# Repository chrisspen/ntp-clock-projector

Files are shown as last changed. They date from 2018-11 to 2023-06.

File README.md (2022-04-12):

NTP Projection Clock
====================

A NodeMCU based clock that wirelessly connects to your network and runs
an NTP client to retrieve the time and project it onto a wall or ceiling.

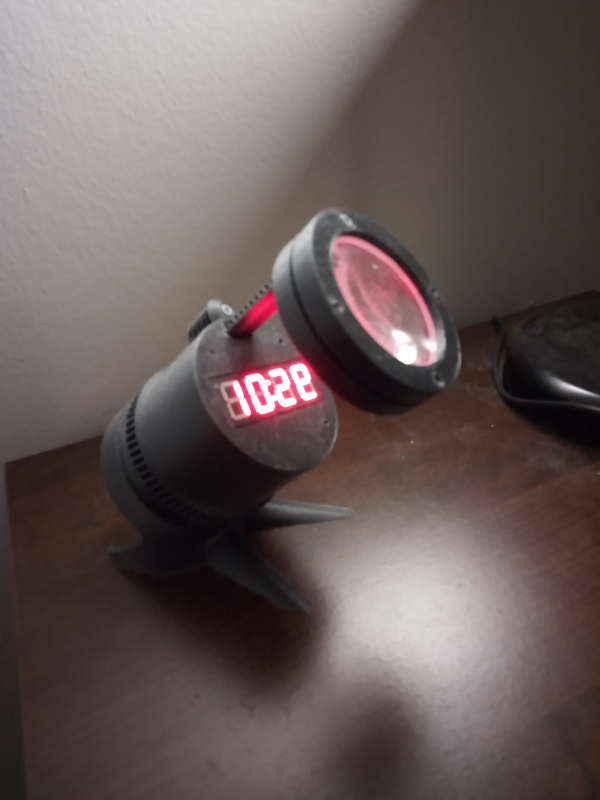
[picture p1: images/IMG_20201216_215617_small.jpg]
ntp projection clock


Construction
------------

Print the [stl files](tree/master/models/printable) that comprise the chassis.

Wire the NodeMCU and Adafruit LED Backback like:

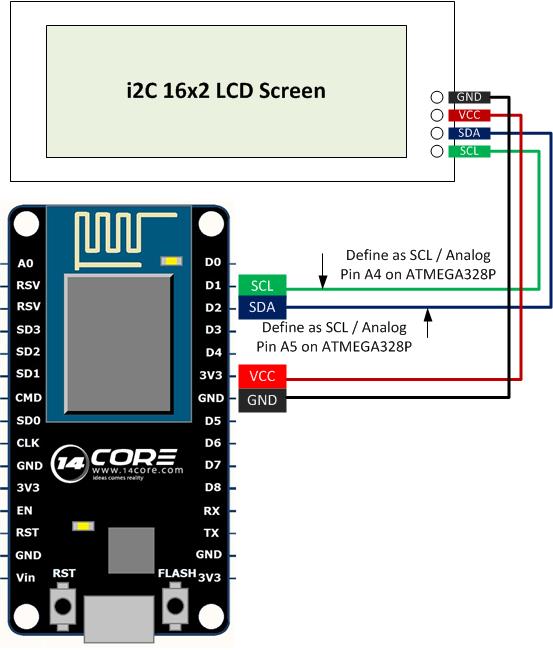
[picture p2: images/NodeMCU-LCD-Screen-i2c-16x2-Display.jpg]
wiring diagram


Screw these boards into the chassis and then plug the NodeMCU into your computer via a USB cable for programming.

The lens I used was the 10x lens piece found ing the <a target="_blank" href="https://www.amazon.com/iMagniphy-Illuminated-Magnifying-Magnifier-Degeneration/dp/B018I1S2Q6/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">iMagniphy Glass</a>. Note, it's actually made of two lens sandwiched in a housing.

Programming
-----------

Install the Arduino IDE 1.8 or later and NodeMCU Arduino support:

    https://www.arduino.cc/

Launch the IDE with:

    cd /usr/share/arduino; arduino

Install [NodeMCU Arduino Support](https://github.com/esp8266/Arduino#installing-with-boards-manager):

* Start Arduino and open Preferences window.
* Enter http://arduino.esp8266.com/stable/package_esp8266com_index.json into Additional Board Manager URLs field. You can add multiple URLs, separating them with commas.
* Open Boards Manager from Tools->Board menu and install or update the esp8266 platform.
* Under Tools->Boards, select "NodeMCU 1.0 (ESP-12E Module)".

Load the `firmware.ino` sketch, select NodeMCU board and board, verify and upload.

To set the Wifi password dynamically, shell into the `scripts` directory and run:

    cd src/scripts
    ./init_virtualenv.sh
    . .env/bin/activate
    ./clock_controller.py login ssid ssidpwd

Otherwise, create the file src/firmware/credentials.h and enter your credentials there, recompile and upload your firmware.

Debugging
---------

To inspect output, select "Serial Monitor" under Tools in Arduino IDE. Select 115200 baudrate.

Also, via the clock_controller.py script with:

    ./clock_controller.py monitor

To get detailed time output:

    ./clock_controller.py time

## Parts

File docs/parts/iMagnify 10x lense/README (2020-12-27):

iMagnify 10x Lense

https://www.amazon.com/gp/product/B018I1S2Q6

iMagniphy LED Illuminated Magnifying Glass Set. Best Magnifier With Lights for Seniors, Macular Degeneration, Reading and Hobbyists (2-Lens (10X + 5X))

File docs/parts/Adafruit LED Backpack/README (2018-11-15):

Adafruit 0.56" 4-Digit 7-Segment Display w/I2C Backpack - Red

https://www.adafruit.com/product/878

https://learn.adafruit.com/adafruit-led-backpack/

https://github.com/adafruit/Adafruit_LED_Backpack

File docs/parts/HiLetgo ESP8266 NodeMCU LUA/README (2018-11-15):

HiLetgo 2pcs ESP8266 NodeMCU LUA CP2102 ESP-12E Internet WIFI Development Board Open source Serial Wireless Module Works Great with Arduino IDE/Micropython (Pack of 2PCS)

ESP8266 ESP-12E NodeMCU

https://www.amazon.com/gp/product/B010N1SPRK

Built-in Micro-USB, with flash and reset switches, easy to program
Full I/O port and Wireless 802.11 supported, direct download no need to reset
Arduino compatible, works great with the latest Arduino IDE/Mongoose IoT/Micropython
Data download access to the website: http://www.nodemcu.com
Firmware link: https://github.com/nodemcu/nodemcu-firmware 

https://www.instructables.com/id/Programming-ESP8266-ESP-12E-NodeMCU-Using-Arduino-/
https://www.instructables.com/id/Quick-Start-to-Nodemcu-ESP8266-on-Arduino-IDE/

https://roboindia.com/tutorials/nodemcu-amica-esp8266-board-installation

https://github.com/esp8266/Arduino
https://github.com/esp8266/Arduino/tree/master/libraries/esp8266/examples/NTP-TZ-DST

I2C
---

https://www.instructables.com/id/ESP8266-I2C-PORT-and-Address-Scanner/

    "I picked D1(GPIO5), and D2(GPIO4) as my bus ports."

    NodeMCU GPIO5 -> SCL (RTC) -> SCL (OLED)
    NodeMCU GPIO4 -> SDA (RTC) -> SDA (OLED)

https://www.14core.com/wiring-nodemcu-esp8266-12e-with-i2c-16x2-lcd-screen/

    the SCL as Arduino Analog Pin A4 is connected to D1 on NodeMCU at the same time
    the D2 as the SDA represent as Analog Pin A5 on Arduino Board

D1 = SDA? SCL?
D2 = SCL? SDA?

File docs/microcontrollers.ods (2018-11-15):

Score | Name | Price | Wifi | Arduino Compatible | Ext Antenna Hookup | Programmable Via USB | GPIO Pins | Logic Level | URL
8.25 | NodeMCU LUA CP2102 ESP-12E | $7 | 1 | 1 | 0 | 1 |  |  | https://www.amazon.com/HiLetgo-Internet-Development-Wireless-Micropython/dp/B010N1SPRK/
5.75 | Adafruit Feather Huzzah with ESP8266 | $17 | 1 |  | 0 | 1 | 9 | 3.3 | https://www.adafruit.com/product/2821
2.00 | SparkFun ESP8266 Thing | $16 | 1 |  | 1 | 0 |  | 3.3 | https://www.sparkfun.com/products/13231
1.25 | Particle PHOTONH | $19 | 1 | 0 | 1 | 0 |  |  | https://www.amazon.com/dp/B016YNU1A0/

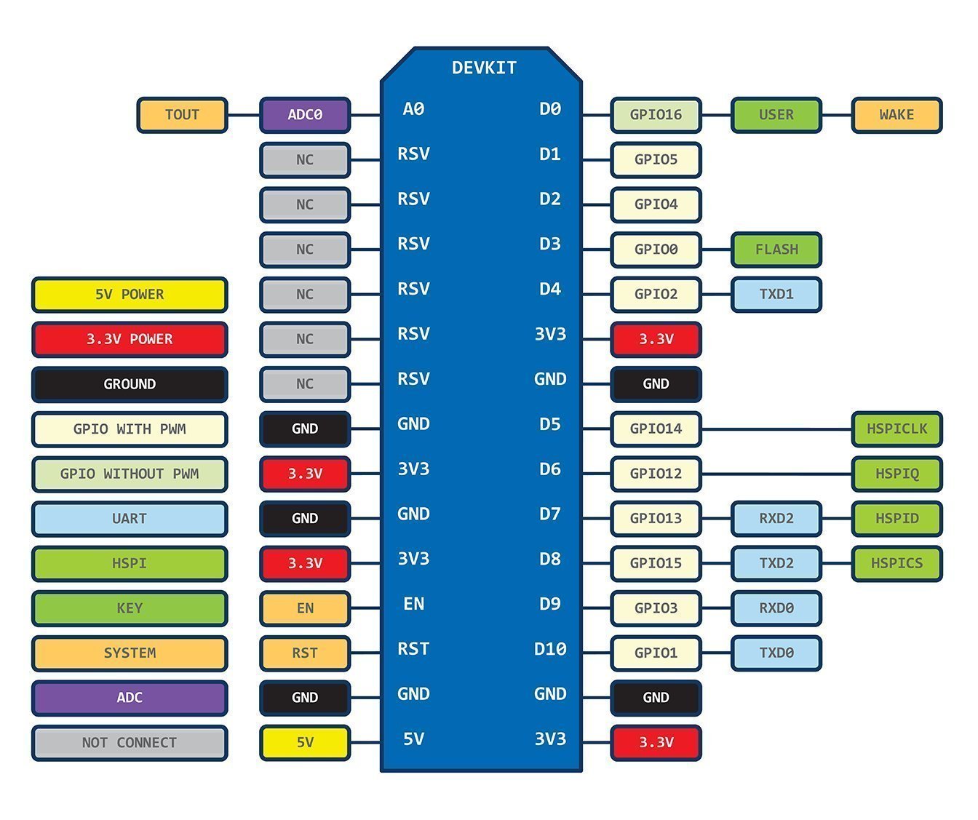
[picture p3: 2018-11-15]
docs/parts/HiLetgo ESP8266 NodeMCU LUA/71SdqCFUfeL._SL1344_.jpg

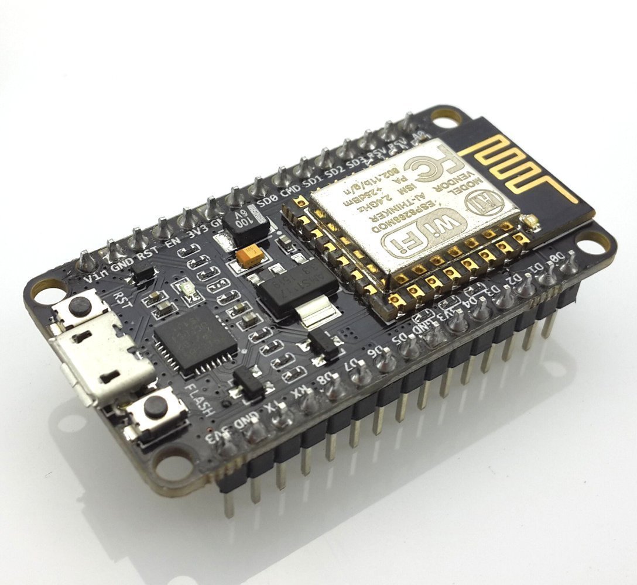
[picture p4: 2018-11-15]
docs/parts/HiLetgo ESP8266 NodeMCU LUA/71JT2nHA8EL._SL1088_.jpg

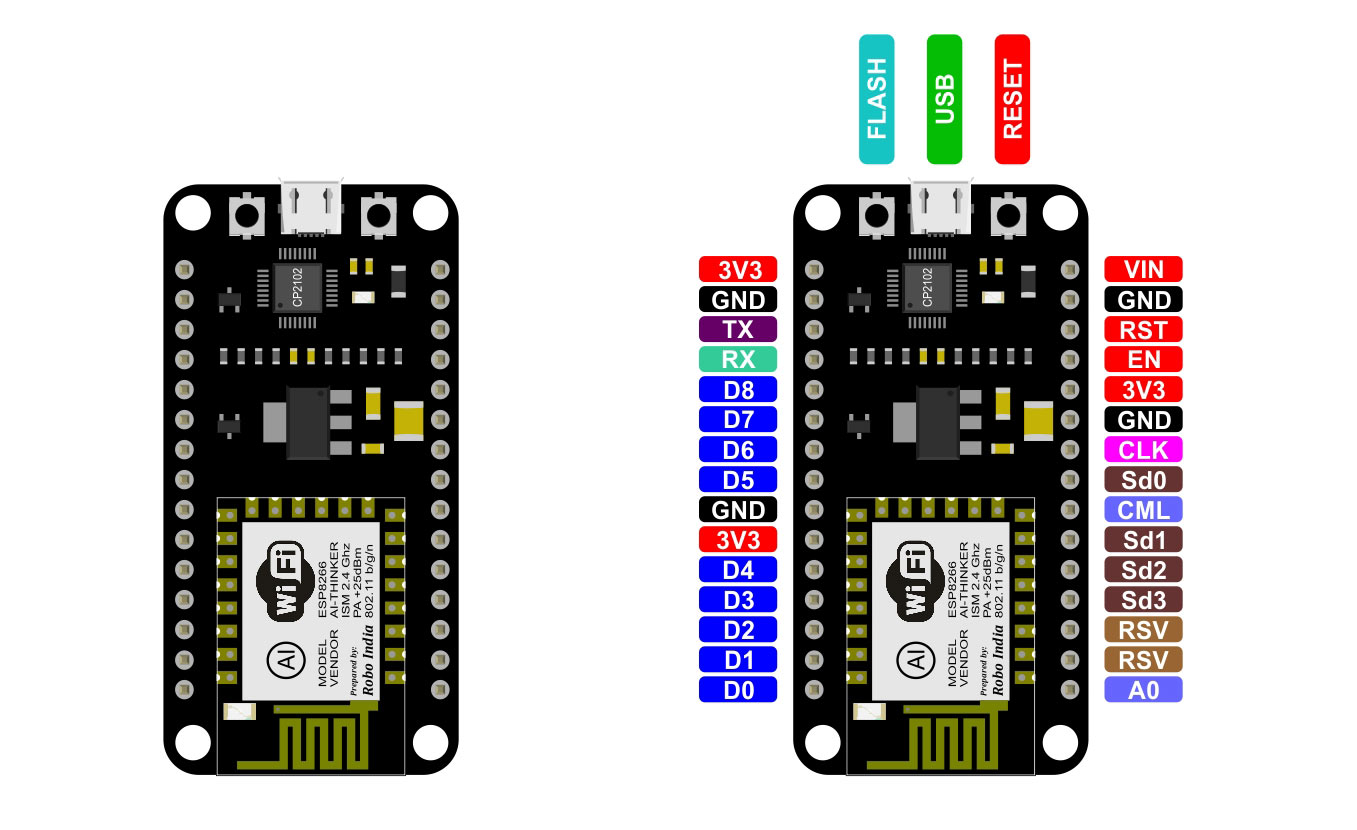
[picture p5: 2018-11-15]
docs/parts/HiLetgo ESP8266 NodeMCU LUA/NODE-MCU-AMICA-2.jpg

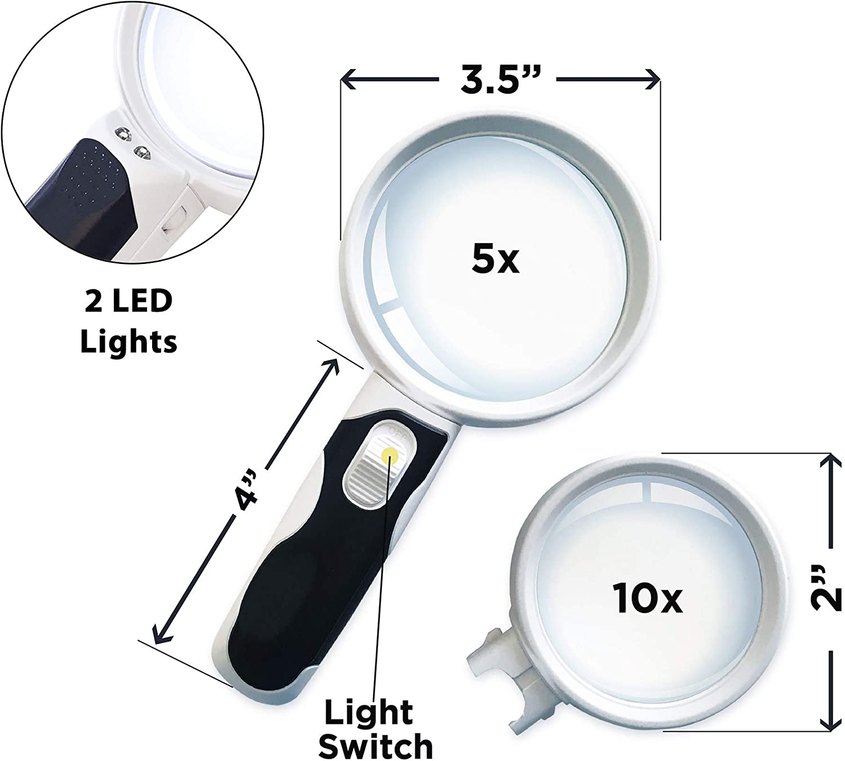
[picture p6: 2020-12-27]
docs/parts/iMagnify 10x lense/714F4Yw+oCL._AC_SL1500_.jpeg

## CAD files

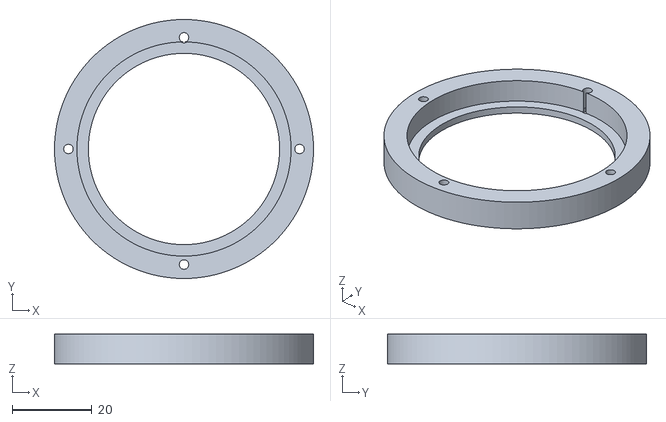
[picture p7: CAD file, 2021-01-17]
models/printable/lens_holder_top.stl
65.0 x 65.0 x 7.50

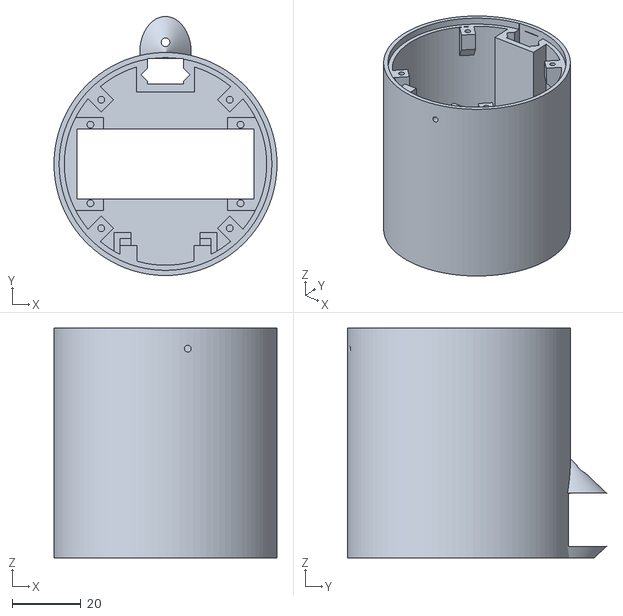
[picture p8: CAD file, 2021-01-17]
models/printable/housing.stl
65.0 x 75.5 x 67.0

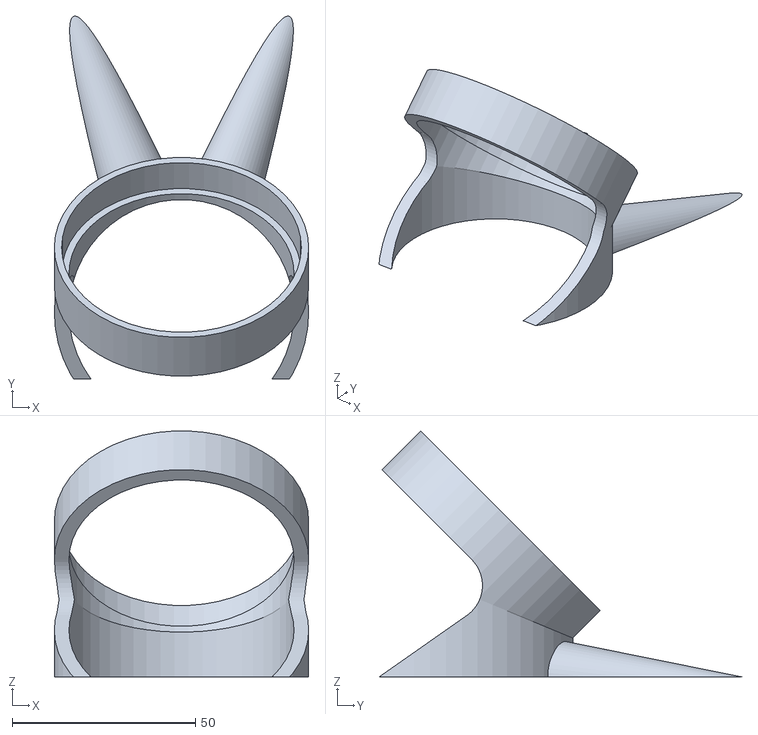
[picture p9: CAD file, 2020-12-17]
models/printable/base.stl
69.5 x 99.2 x 67.2

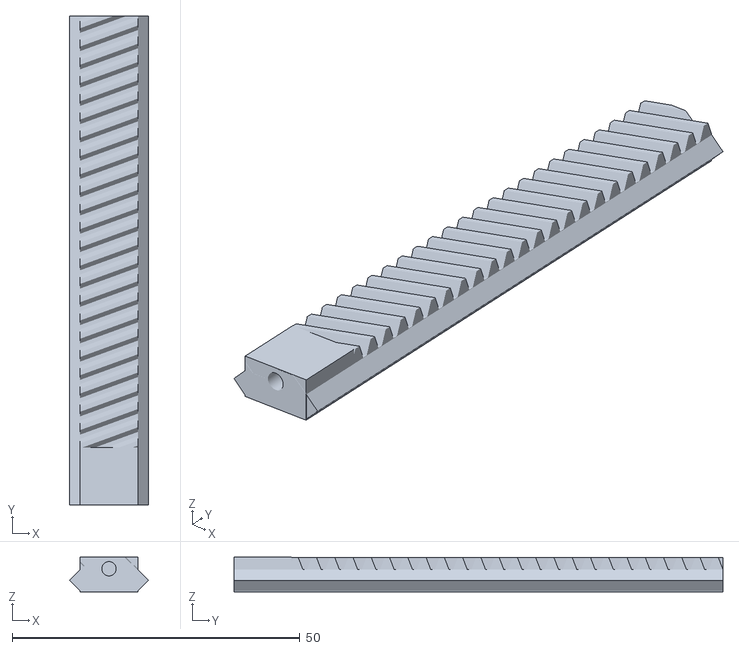
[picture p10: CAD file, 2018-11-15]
models/printable/rack.stl
13.7 x 85.0 x 6.00

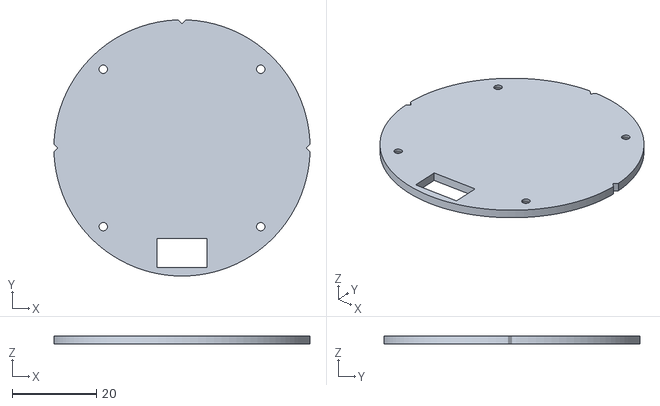
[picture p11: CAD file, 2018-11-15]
models/printable/housing_lid.stl
60.9 x 61.0 x 2.00

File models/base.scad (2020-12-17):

module make_base(){
    base_h = 25;
    inner_d = 65.5;
    thickness = 2;
    
    difference(){
        union(){
            // top
            if(1){
            difference(){
                translate([0,0,base_h])
                rotate([-45,0,0])
                translate([0,0,base_h/2]){
                    difference(){
                        cylinder(d=65.5+thickness*2, h=base_h, center=true, $fn=50);
                        cylinder(d=65.5-thickness*2, h=base_h*2, center=true, $fn=50);
                        
                        // clock cutout
                        color("red")
                        //translate([-10,0,0])
                        translate([0,0,base_h*1.5-10])
                        cylinder(d=65.5, h=base_h*2, center=true, $fn=50);
                    }
                }
                
                if(1)
                translate([0,0,base_h])
                rotate([-45/2,0,0])
                translate([0,0,-100/2])
                cube([300,300,100], center=true);
            }
            }
            
            // bottom
            if(1)
            intersection(){
                translate([0,0,base_h/2]){
                    difference(){
                        cylinder(d=65.5+thickness*2, h=base_h, center=true, $fn=50);
                        cylinder(d=65.5-thickness*2, h=base_h*2, center=true, $fn=50);
                    }
                }
                
                translate([0,0,base_h])
                rotate([-45/2,0,0])
                translate([0,0,-100/2])
                cube([300,300,100], center=true);
            }
        }
        
        // notch cutout
        translate([0,0,base_h])
        color("blue"){
            //translate([0,0,base_h-20/2])
            rotate([0,90,0])
            cylinder(d=20, h=100, center=true, $fn=50);
            
            //cube([10,10,10], center=true);
            
            rotate([-45,0,0])
            translate([0,-40*2/2,0])
            cube([200,40*2,20], center=true);
            
            rotate([35,0,0])
            translate([0,-40*2/2,60/2-20/2])
            cube([200,40*2,60], center=true);
        
        }

    }// end diff
    
    if(0)
    color("blue")
    translate([0,0,base_h])
    rotate([-45/2,0,0])
    translate([0,-40,0])
    scale([1,2,1])
    rotate([0,90,0])
    cylinder(d=50, h=100, center=true, $fn=50);

    // stabilization foot
    for(i=[-1:2:1])
    rotate([0,0,20*i])
    difference(){
        translate([0,65/2,0])
        rotate([-90-5,0,0])
        cylinder(d1=20, d2=0, h=100, $fn=50);
        translate([0,0,-100/2])
        cube([300,300,100], center=true);
    }

}

make_base();

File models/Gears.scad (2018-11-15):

$fn = 96;

/* Bibliothek für Evolventen-Zahnräder, Schnecken und Zahnstangen

Enthält die Module
- rack(modul, length, hoehe, width, pressure_angle=20, gradient_angle=0)
- spur_gear(modul, tooth_number, width, bohrung, pressure_angle=20, gradient_angle=0, optimized=true)
- arrow_gear(modul, tooth_number, width, bohrung, pressure_angle=20, gradient_angle=0, optimized=true)
- rack_und_rad (modul, laenge_stange, zahnzahl_rad, hoehe_stange, bohrung_rad, width, pressure_angle=20, gradient_angle=0, zusammen_gebaut=true, optimized=true)
- ring_gear(modul, tooth_number, width, randbreite, pressure_angle=20, gradient_angle=0)
- arrow_ring_gear(modul, tooth_number, width, randbreite, pressure_angle=20, gradient_angle=0)
- planetary_gear(modul, zahnzahl_sonne, zahnzahl_planet, anzahl_planeten, width, randbreite, bohrung, pressure_angle=20, gradient_angle=0, zusammen_gebaut=true, optimized=true)
- bevel_gear(modul, tooth_number,  teilkegelwinkel, zahnbreite, bohrung, pressure_angle=20, gradient_angle=0)
- bevel_arrow_gear(modul, tooth_number, teilkegelwinkel, zahnbreite, bohrung, pressure_angle=20, gradient_angle=0)
- bevel_gear_pair(modul, zahnzahl_rad, zahnzahl_ritzel, achsenwinkel=90, zahnbreite, bohrung, pressure_angle = 20, gradient_angle=0, zusammen_gebaut=true)
- bevel_arrow_gear_pair(modul, zahnzahl_rad, zahnzsahl_ritzel, achsenwinkel=90, zahnbreite, bohrung, pressure_angle = 20, gradient_angle=0, zusammen_gebaut=true)
- worm(modul, gangzahl, length, bohrung, pressure_angle=20, gradient_angle=10, zusammen_gebaut=true)
- worm_gear(modul, tooth_number, gangzahl, width, length, bohrung_schnecke, bohrung_rad, pressure_angle=20, gradient_angle=0, optimized=true, zusammen_gebaut=true)

Beispiele für jedes Modul befinden sich auskommentiert am Ende dieser Datei

Autor:      Dr Jörg Janssen
Stand:      1. Juni 2018
Version:    2.2
Lizenz:     Creative Commons - Attribution, Non Commercial, Share Alike

Erlaubte Module nach DIN 780:
0.05 0.06 0.08 0.10 0.12 0.16
0.20 0.25 0.3  0.4  0.5  0.6
0.7  0.8  0.9  1    1.25 1.5
2    2.5  3    4    5    6
8    10   12   16   20   25
32   40   50   60

*/


// Allgemeine Variablen
pi = 3.14159;
rad = 57.29578;
spiel = 0.05;   // Spiel zwischen Zähnen

/*  Wandelt Radian in Grad um */
function grad(pressure_angle) = pressure_angle*rad;

/*  Wandelt Grad in Radian um */
function radian(pressure_angle) = pressure_angle/rad;

/*  Wandelt 2D-Polarkoordinaten in kartesische um
    Format: radius, phi; phi = Winkel zur x-Achse auf xy-Ebene */
function pol_zu_kart(polvect) = [
    polvect[0]*cos(polvect[1]),  
    polvect[0]*sin(polvect[1])
];

/*  Kreisevolventen-Funktion:
    Gibt die Polarkoordinaten einer Kreisevolvente aus
    r = Radius des Grundkreises
    rho = Abrollwinkel in Grad */
function ev(r,rho) = [
    r/cos(rho),
    grad(tan(rho)-radian(rho))
];

/*  Kugelevolventen-Funktion
    Gibt den Azimutwinkel einer Kugelevolvente aus
    theta0 = Polarwinkel des Kegels, an dessen Schnittkante zur Großkugel die Evolvente abrollt
    theta = Polarwinkel, für den der Azimutwinkel der Evolvente berechnet werden soll */
function kugelev(theta0,theta) = 1/sin(theta0)*acos(cos(theta)/cos(theta0))-acos(tan(theta0)/tan(theta));

/*  Wandelt Kugelkoordinaten in kartesische um
    Format: radius, theta, phi; theta = Winkel zu z-Achse, phi = Winkel zur x-Achse auf xy-Ebene */
function kugel_zu_kart(vect) = [
    vect[0]*sin(vect[1])*cos(vect[2]),  
    vect[0]*sin(vect[1])*sin(vect[2]),
    vect[0]*cos(vect[1])
];

/*  prüft, ob eine Zahl gerade ist
    = 1, wenn ja
    = 0, wenn die Zahl nicht gerade ist */
function istgerade(zahl) =
    (zahl == floor(zahl/2)*2) ? 1 : 0;

/*  größter gemeinsamer Teiler
    nach Euklidischem Algorithmus.
    Sortierung: a muss größer als b sein */
function ggt(a,b) = 
    a%b == 0 ? b : ggt(b,a%b);

/*  Polarfunktion mit polarwinkel und zwei variablen */
function spirale(a, r0, phi) =
    a*phi + r0; 

/*  Kopiert und dreht einen Körper */
module kopiere(vect, zahl, abstand, winkel){
    for(i = [0:zahl-1]){
        translate(v=vect*abstand*i)
            rotate(a=i*winkel, v = [0,0,1])
                children(0);
    }
}

/*  rack
    modul = Höhe des Zahnkopfes über der Wälzgeraden
    length = Länge der rack
    hoehe = Höhe der rack bis zur Wälzgeraden
    width = Breite eines Zahns
    pressure_angle = Eingriffswinkel, Standardwert = 20° gemäß DIN 867. Sollte nicht größer als 45° sein.
    gradient_angle = Schrägungswinkel zur Zahnstangen-Querachse; 0° = Geradverzahnung */
module rack(modul, length, hoehe, width, pressure_angle = 20, gradient_angle = 0) {

    // Dimensions-Berechnungen
    modul=modul*(1-spiel);
    c = modul / 6;                                              // Kopfspiel
    mx = modul/cos(gradient_angle);                          // Durch Schrägungswinkel verzerrtes modul in x-Richtung
    a = 2*mx*tan(pressure_angle)+c*tan(pressure_angle);       // Flankenbreite
    b = pi*mx/2-2*mx*tan(pressure_angle);                      // Kopfbreite
    x = width*tan(gradient_angle);                          // Verschiebung der Oberseite in x-Richtung durch Schrägungswinkel
    nz = ceil((length+abs(2*x))/(pi*mx));                       // Anzahl der Zähne
    
    translate([-pi*mx*(nz-1)/2-a-b/2,-modul,0]){
        intersection(){                                         // Erzeugt ein Prisma, das in eine Quadergeometrie eingepasst wird
            kopiere([1,0,0], nz, pi*mx, 0){
                polyhedron(
                    points=[[0,-c,0], [a,2*modul,0], [a+b,2*modul,0], [2*a+b,-c,0], [pi*mx,-c,0], [pi*mx,modul-hoehe,0], [0,modul-hoehe,0], // Unterseite
                        [0+x,-c,width], [a+x,2*modul,width], [a+b+x,2*modul,width], [2*a+b+x,-c,width], [pi*mx+x,-c,width], [pi*mx+x,modul-hoehe,width], [0+x,modul-hoehe,width]],   // Oberseite
                    faces=[[6,5,4,3,2,1,0],                     // Unterseite
                        [1,8,7,0],
                        [9,8,1,2],
                        [10,9,2,3],
                        [11,10,3,4],
                        [12,11,4,5],
                        [13,12,5,6],
                        [7,13,6,0],
                        [7,8,9,10,11,12,13],                    // Oberseite
                    ]
                );
            };
            translate([abs(x),-hoehe+modul-0.5,-0.5]){
                cube([length,hoehe+modul+1,width+1]);          // Quader, der das Volumen der rack umfasst
            }   
        };
    };  
}

/*  Stirnrad
    modul = Höhe des Zahnkopfes über dem Teilkreis
    tooth_number = Anzahl der Radzähne
    width = Zahnbreite
    bohrung = Durchmesser der Mittelbohrung
    pressure_angle = Eingriffswinkel, Standardwert = 20° gemäß DIN 867. Sollte nicht größer als 45° sein.
    gradient_angle = Schrägungswinkel zur Rotationsachse; 0° = Geradverzahnung
    optimized = Löcher zur Material-/Gewichtsersparnis bzw. Oberflächenvergößerung erzeugen, wenn Geometrie erlaubt */
module spur_gear(modul, tooth_number, width, bohrung, pressure_angle = 20, gradient_angle = 0, optimized = true) {
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

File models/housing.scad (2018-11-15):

use <layout.scad>;

translate([0,0,0])
rotate([0,180,0])
clock_housing();

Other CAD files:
models/printable/lens_holder_bottom.stl
models/housing_lid.scad
models/layout.scad
models/lens_holder_bottom.scad
models/lens_holder_top.scad
models/lens_worm_gear.scad
models/light_mask.scad
models/rack.scad

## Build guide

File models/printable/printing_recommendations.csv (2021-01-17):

filename | wall_thickness | color | infill_percent | platform_adhesion | support_type | obsolete
base.stl |  |  |  |  |  | 0
housing.stl |  |  |  |  |  | 0
housing_lid.stl |  |  |  |  |  | 0
lens_holder_bottom.stl |  |  |  |  |  | 0
lens_holder_bottom2.stl |  |  |  |  |  | 1
lens_holder_bottom3.stl |  |  |  |  |  | 1
lens_holder_top.stl |  |  |  |  |  | 0
lens_holder_top2.stl |  |  |  |  |  | 1
lens_holder_top3.stl |  |  |  |  |  | 1
lens_worm_gear.stl |  |  |  |  |  | 0
light_mask_test_20180911.stl |  |  |  |  |  | 1
light_mask_test_20180911b.stl |  |  |  |  |  | 1
rack.stl |  |  |  |  |  | 0

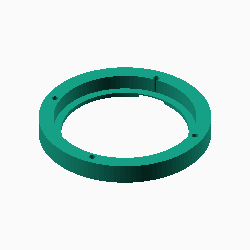
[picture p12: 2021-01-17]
models/printable/lens_holder_bottom.png

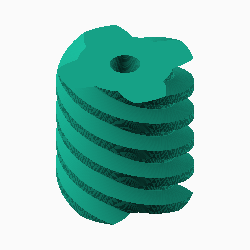
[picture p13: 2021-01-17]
models/printable/lens_worm_gear.png

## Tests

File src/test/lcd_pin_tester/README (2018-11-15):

Writes the servo position to serial.

Compile and upload with:

    make && make upload

To view values:

    make monitor

Then press ctrl + a and then a capital K and press y when it asks if you really want to kill the session.

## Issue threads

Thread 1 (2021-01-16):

Wiring diagram?

Doridian, 2021-01-16:

chrisspen, 2021-01-17:
I was wondering if someone would ask for this. It sounds like you've already figured it out. Yes 3V3 is fine.

The wiring's very simple and is essentially identical to [this diagram](https://github.com/chrisspen/ntp-clock-projector/blob/master/docs/parts/HiLetgo%20ESP8266%20NodeMCU%20LUA/NodeMCU-LCD-Screen-i2c-16x2-Display.jpg).

To summarize:

NodeMCU Gnd -> LED Backpack Gnd
NodeMCU 3V3 -> LED Backpack VCC
NodeMCU D1 (SCL) -> LED Backpack SCL
NodeMCU D2 (SDA) -> LED Backpack SDA

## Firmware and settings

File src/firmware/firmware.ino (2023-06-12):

/*
 * Copyright 2018 Chris Spencer (chrisspen@gmail.com)
 *
 * Firmware for the NTP Projection Clock.
*/

#include <ESP8266WiFi.h>
#include <time.h>                       // time() ctime()
#include <sys/time.h>                   // struct timeval
#include <coredecls.h>                  // settimeofday_cb()
#include <TZ.h>
#include <Wire.h>
#include "Adafruit_GFX.h"
#include "Adafruit_LEDBackpack.h"
// #include "EEPROMAnything.h"
#include "EEPROM.h"

#include "credentials.h"

////////////////////////////////////////////////////////

#define CLOCK_UPDATE_T 500

#define MYTZ TZ_America_Los_Angeles

// Persistent variables.
struct config_t {
    char ssid[255]="";
    char ssidpwd[225]="";
} configuration;

unsigned long last_clock_update = 0;

#define COMMAND_SET_LOGIN 'l'
#define COMMAND_GET_LOGIN 'k'
#define COMMAND_GET_TIME 't'
#define COMMAND_END '\n'
#define COMMAND_SEP ':'

// #define TZ              -5 // -5=EST      // (utc+) TZ in hours
// #define DST_MN          60      // use 60mn for summer time in some countries

#define NTP0_OR_LOCAL1  0       // 0:use NTP  1:fake external RTC
#define RTC_TEST        1510592825

// #define TZ_MN           ((TZ)*60)
// #define TZ_SEC          ((TZ)*3600)
// #define DST_SEC         ((DST_MN)*60)

#define DISCONNECTED_T 100
#define CONNECTED_T 1000

unsigned long last_blink_time = 0;

timeval cbtime;         // time set in callback
bool cbtime_set = false;

Adafruit_7segment matrix = Adafruit_7segment();

unsigned long last_colon_blink = 0;
bool colon = true;

void write_time(const tm* tm) {
    if (WiFi.status() != WL_CONNECTED) {
        if (millis() - last_blink_time >= DISCONNECTED_T) {
            // If disconnected from wifi, blink colon quickly.
            digitalWrite(LED_BUILTIN, !digitalRead(LED_BUILTIN));
            colon = !colon;
            last_blink_time = millis();
        }
        matrix.writeDigitNumMirrored(0, 8, false);
        matrix.writeDigitNumMirrored(1, 8, false);
        matrix.drawColon(colon);
        matrix.writeDigitNumMirrored(3, 8, false);
        matrix.writeDigitNumMirrored(4, 8, false);
    } else {
        if (millis() - last_blink_time >= CONNECTED_T) {
            // If disconnected from wifi, blink colon slowly.
            digitalWrite(LED_BUILTIN, !digitalRead(LED_BUILTIN));
            colon = !colon;
            last_blink_time = millis();
        }
        int minute1 = tm->tm_min/1%10;
        int minute2 = tm->tm_min/10%10;
        int hour = tm->tm_hour;

        // if(!tm->tm_isdst){
        //     hour -= 1; // Unapply DST hour?
        // }

        // Truncate time to 12 hour clock format.
        hour = hour % 12;
        if (hour == 0 || hour == 12 || hour == 24) {
          hour = 12;
        }

        int hour1 = hour/1%10;
        int hour2 = hour/10%10;
        matrix.writeDigitNumMirrored(0, minute1, false);  // minute, low digit
        matrix.writeDigitNumMirrored(1, minute2, false);  // minute, high digit
        matrix.drawColon(colon);
        matrix.writeDigitNumMirrored(3, hour1, false);  // hour, low digit
        if (hour2) {
          matrix.writeDigitNumMirrored(4, hour2, false);  // hour, high digit
        } else {
          matrix.turnOffDigit(4);
        }
    }
    matrix.writeDisplay();
}

void time_is_set(void) {
  gettimeofday(&cbtime, NULL);
  cbtime_set = true;
}

void save_configuration() {
//  EEPROM_writeAnything(0, configuration);
    EEPROM.begin(sizeof(configuration));
    EEPROM.put(0,configuration);
    EEPROM.commit();
    EEPROM.end();
}

void load_configuration() {
    EEPROM.begin(sizeof(configuration));
    EEPROM.get(0,configuration);
    EEPROM.end();
}

String getValue(String data, char separator, int index) {
    int found = 0;
    int strIndex[] = { 0, -1 };
    int maxIndex = data.length() - 1;

    for (int i = 0; i <= maxIndex && found <= index; i++) {
        if (data.charAt(i) == separator || i == maxIndex) {
            found++;
            strIndex[0] = strIndex[1] + 1;
            strIndex[1] = (i == maxIndex) ? i+1 : i;
        }
    }
    return found > index ? data.substring(strIndex[0], strIndex[1]) : "";
}

void setup() {
    load_configuration();

    // https://github.com/esp8266/Arduino/blob/master/libraries/Wire/Wire.cpp
    // On the esp8266, you can manually specify the i2c pins.
    Wire.begin();  // SDA=A5=D2, SCL=A4=D1

    last_blink_time = 0;

    pinMode(LED_BUILTIN, OUTPUT);
    digitalWrite(LED_BUILTIN, LOW);

    matrix.begin(0x70);

    Serial.begin(115200);
    settimeofday_cb(time_is_set);

    // configTime(TZ_SEC, DST_SEC, "pool.ntp.org");
    configTime(MYTZ, "pool.ntp.org");
    WiFi.mode(WIFI_STA);
    WiFi.begin(configuration.ssid, configuration.ssidpwd);
}

// for testing purpose:
extern "C" int clock_gettime(clockid_t unused, struct timespec *tp);

#define PTM(w) \
  Serial.print(":" #w "="); \
  Serial.print(tm->tm_##w);

void printTm(const char* what, const tm* tm) {
  Serial.print(what);
  PTM(isdst); PTM(yday); PTM(wday);
  PTM(year);  PTM(mon);  PTM(mday);
  PTM(hour);  PTM(min);  PTM(sec);
}

timeval tv;
timespec tp;
time_t now;
uint32_t now_ms, now_us;

String read_buffer = "";
char read_byte;
int bytes_read = 0;
unsigned long last_buffer_read = 0;
char current_command;
bool current_command_done = false;

void print_serial_login() {
  Serial.println(String("SSID=") + String(configuration.ssid) +
    String(":SSIDPWD=") + String(configuration.ssidpwd));
  Serial.flush();
}

void print_serial_time() {
  printTm("LOCALTIME=", localtime(&now));
  Serial.println();
  Serial.flush();
}

void loop() {
  if (millis() - last_clock_update >= CLOCK_UPDATE_T) {
    last_clock_update = millis();

    gettimeofday(&tv, nullptr);
    clock_gettime(0, &tp);
    now = time(nullptr);
    now_ms = millis();
    now_us = micros();

    /*/ localtime / gmtime every second change
    static time_t lastv = 0;
    if (lastv != tv.tv_sec) {
      lastv = tv.tv_sec;
      Serial.println();
      printTm("localtime", localtime(&now));
      Serial.println();
      printTm("gmtime   ", gmtime(&now));
      Serial.println();
      Serial.println();
    }
    */

  /*
    // time from boot
    Serial.print("clock:");
    Serial.print((uint32_t)tp.tv_sec);
    Serial.print("/");
    Serial.print((uint32_t)tp.tv_nsec);
    Serial.print("ns");

    // time from boot
    Serial.print(" millis:");
    Serial.print(now_ms);
    Serial.print(" micros:");
    Serial.print(now_us);

    // EPOCH+tz+dst
    Serial.print(" gtod:");
    Serial.print((uint32_t)tv.tv_sec);
    Serial.print("/");
    Serial.print((uint32_t)tv.tv_usec);
    Serial.print("us");

    // EPOCH+tz+dst
    Serial.print(" time:");
    Serial.print((uint32_t)now);

    // human readable
    Serial.print(" ctime:(UTC+");
    Serial.print((uint32_t)(TZ * 60 + DST_MN));
    Serial.print("mn)");
    Serial.print(ctime(&now));
  */

    write_time(localtime(&now));
  }

  while (Serial.available()) {
    last_buffer_read = millis();

    // If we don't have a command, then the first byte specifies the command.
    if (bytes_read == 0) {
      current_command = Serial.read();
      bytes_read += 1;
      continue;
    }

    // Otherwise, read argument data.
    read_byte = Serial.read();
    bytes_read += 1;

    // Collect arguments.
    if (read_byte == COMMAND_END) {
      // Terminator received, so begin executing.
      current_command_done = true;
    } else if (current_command == COMMAND_SET_LOGIN) {
      // Read arguments.
      read_buffer += read_byte;
    } else if (current_command == COMMAND_GET_LOGIN) {
      // No arguments. Act immediately.
      current_command_done = true;
    } else if (current_command == COMMAND_GET_TIME) {
      // No arguments. Act immediately.
      current_command_done = true;
    } else {
      // Unknown command received.
      current_command = '\0';
    }

    // Execute command.
    if (current_command_done) {
      current_command_done = false;
      if (current_command == COMMAND_SET_LOGIN) {
        strcpy(configuration.ssid,
            getValue(read_buffer, COMMAND_SEP, 0).c_str());
        strcpy(configuration.ssidpwd,
            getValue(read_buffer, COMMAND_SEP, 1).c_str());
        print_serial_login();
        save_configuration();
        WiFi.begin(configuration.ssid, configuration.ssidpwd);
      } else if (current_command == COMMAND_GET_LOGIN) {
        print_serial_login();
      } else if (current_command == COMMAND_GET_TIME) {
        print_serial_time();
      }
      break;
    }
  }

  // If we don't read anything after 5 seconds, then reset read buffer.
  if (millis() - last_buffer_read >= 5000 || current_command_done) {
    read_buffer = "";
    bytes_read = 0;
    current_command = '\0';
    current_command_done = false;
  }
}

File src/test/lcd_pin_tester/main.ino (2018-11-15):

/*
Attach a 30k-50k resistor to between each Com pin and ground.
// 50k=>2.7V avg
// 30k=>2.3V avg
// http://ww1.microchip.com/downloads/en/AppNotes/doc8103.pdf
// http://www.arduinoos.com/2014/08/lcd-direct-driving/

The connector has 12 pins, but one appears to be disconnected, and has no signal, leaving effectively just 11 pins.
We likely have 2 backplanes, which leaves 9 segment driver pins.

Minimum pulse width appears to be 4ms = 0.004sec => would need frequency of 250 Hz

*/

#define LED_PIN 13

#define COM0_PIN 3 //b0 orig
//#define COM0_PIN 12 //b0
//#define COM0_PIN 13 //b0
#define COM1_PIN 4 //b5 orig
//#define COM1_PIN 12 //b5
//#define COM1_PIN 13 //b5
#define COM2_PIN 5 //r1 orig
//#define COM2_PIN 12 //r1
//#define COM2_PIN 13 //r1
#define COM3_PIN 6 //r5 orig
//#define COM3_PIN 12 //r5
//#define COM3_PIN 13 //r5

#define SEG0_PIN 7 //b1 = confirmed control
#define SEG1_PIN 8 //b2 = confirmed control
#define SEG2_PIN 9 //b3 = confirmed control
#define SEG3_PIN 10 //r3 = confirmed control
#define SEG4_PIN 11 //r4 = confirmed control

#define SEG5_PIN 12 //b4 = swap?
//swap with b5=bad
//#define SEG5_PIN 4 //b4
//swap with b0=bad
//#define SEG5_PIN 3 //b4
//swap with r1=bad
//#define SEG5_PIN 5 //b4
//swap with r5=bad
//#define SEG5_PIN 6 //b4

#define SEG6_PIN 13 //r2 = swap?
//swap with b5=bad
//#define SEG6_PIN 4 //r2
//swap with b0=bad
//#define SEG6_PIN 3 //r2
//swap with r1=bad
//#define SEG6_PIN 5 //r2
//swap with r5=
//#define SEG6_PIN 6 //r2

//#define SEG7_PIN 2 //r0 //unused?

#define FRAME_MS 16
#define PULSE_MS 2
#define UPDATE_MS 1

#define NUM_BACKPLANES 4
#define NUM_CONTROLS 7

int backplane_pins[NUM_BACKPLANES] = {COM0_PIN, COM1_PIN, COM2_PIN, COM3_PIN};
int control_pins[NUM_CONTROLS] = {SEG0_PIN, SEG1_PIN, SEG2_PIN, SEG3_PIN, SEG4_PIN, SEG5_PIN, SEG6_PIN};//, SEG7_PIN};

enum PinState {
	ON,
	OFF,
	DISCONNECTED
};

unsigned long last_blink = 0;

unsigned long last_clock_update = 0;

//unsigned long last_update = 0;
//PinState state = DISCONNECTED; // 0=low, 1=high, 2=disconnected
//unsigned long offset = 0; // should be in multiples of PULSE_MS

//bool segment0_state = true;

int current_backplane_index = 0;
PinState current_backplane_state = OFF;
unsigned long last_backplane_update = 0;

//bool control0_status[NUM_BACKPLANES] = {1,1,1,1};//1st
//bool control1_status[NUM_BACKPLANES] = {1,1,1,1};//2nd "1:"
//bool control2_status[NUM_BACKPLANES] = {1,1,1,1};//3rd,4th lower right
//bool control3_status[NUM_BACKPLANES] = {1,1,1,1};
//bool control4_status[NUM_BACKPLANES] = {1,1,1,1};
//bool control5_status[NUM_BACKPLANES] = {1,1,1,1};
//bool control6_status[NUM_BACKPLANES] = {1,0,1,1};
//bool control7_status[NUM_BACKPLANES] = {1,1,1,1};//na

bool control_status[NUM_BACKPLANES*NUM_CONTROLS] = {
	//2A:PA pm
	//1,1,1,1,
	//1,1,1,1,
	//1,1,1,1,
	//1,1,1,1,
	//1,1,1,1,
	//1,1,1,1,
	//1,1,1,1
	//oA:PA pm
	//0,1,1,1,
	//1,1,1,1,
	//1,1,1,1,
	//1,1,1,1,
	//1,1,1,1,
	//1,1,1,1,
	//1,1,1,1
	//dA:PA
	//1,0,1,1,
	//1,1,1,1,
	//1,1,1,1,
	//1,1,1,1,
	//1,1,1,1,
	//1,1,1,1,
	//1,1,1,1
	//1A:PA pm
	//1,1,0,1,
	//1,1,1,1,
	//1,1,1,1,
	//1,1,1,1,
	//1,1,1,1,
	//1,1,1,1,
	//1,1,1,1
	//dA:PA pm
	//1,1,1,0,
	//1,1,1,1,
	//1,1,1,1,
	//1,1,1,1,
	//1,1,1,1,
	//1,1,1,1,
	//1,1,1,1
	//dA:PA pm fading
	//1,0,1,0,
	//1,1,1,1,
	//1,1,1,1,
	//1,1,1,1,
	//1,1,1,1,
	//1,1,1,1,
	//1,1,1,1
	//2P:PA pm
	//1,1,1,1,
	//0,1,1,1,
	//1,1,1,1,
	//1,1,1,1,
	//1,1,1,1,
	//1,1,1,1,
	//1,1,1,1
	//dP:PA
	//1,0,1,1,
	//0,1,1,1,
	//1,1,1,1,
	//1,1,1,1,
	//1,1,1,1,
	//1,1,1,1,
	//1,1,1,1
	//2h:PA
	//1,1,1,1,
	//1,0,1,1,
	//1,1,1,1,
	//1,1,1,1,
	//1,1,1,1,
	//1,1,1,1,
	//1,1,1,1
	//2A PA
	//1,1,1,1,
	//1,1,0,1,
	//1,1,1,1,
	//1,1,1,1,
	//1,1,1,1,
	//1,1,1,1,
	//1,1,1,1
	//2A:PA pm
	//1,1,1,1,
	//1,1,1,0,
	//1,1,1,1,
	//1,1,1,1,
	//1,1,1,1,
	//1,1,1,1,
	//1,1,1,1
	//2A:NA pm
	//1,1,1,1,
	//1,1,1,1,
	//0,1,1,1,
	//1,1,1,1,
	//1,1,1,1,
	//1,1,1,1,
	//1,1,1,1
	//2A:Ah pm
	//1,1,1,1,
	//1,1,1,1,
	//1,0,1,1,
	//1,1,1,1,
	//1,1,1,1,
	//1,1,1,1,
	//1,1,1,1
	//2A:hA pm
	//1,1,1,1,
	//1,1,1,1,
	//1,1,0,1,
	//1,1,1,1,
	//1,1,1,1,
	//1,1,1,1,
	//1,1,1,1
	//2A:AH pm
	//1,1,1,1,
	//1,1,1,1,
	//1,1,1,0,
	//1,1,1,1,
	//1,1,1,1,
	//1,1,1,1,
	//1,1,1,1
	//2A:9A pm broken
	//1,1,1,1,
	//1,1,1,1,
	//1,1,1,1,
	//0,1,1,1,
	//1,1,1,1,
	//1,1,1,1,
	//1,1,1,1
	//2A:2A pm
	//1,1,1,1,
	//1,1,1,1,
	//1,1,1,1,
	//1,0,1,1,
	//1,1,1,1,
	//1,1,1,1,
	//1,1,1,1
	//C
	//0,0,0,0,
	//0,0,0,0,
	//0,0,0,0,
	//0,0,1,0,
	//0,0,0,0,
	//0,0,0,0,
	//0,0,0,0,
	//C
	//0,0,0,0,
	//0,0,0,0,
	//0,0,0,0,
	//0,0,0,1,
	//0,0,0,0,
	//0,0,0,0,
	//0,0,0,0,
	//C
	//0,0,0,0,
	//0,0,0,0,
	//0,0,0,0,
	//1,1,1,1,
	//0,0,0,0,
	//0,0,0,0,
	//0,0,0,0,
	//part __45
	//0,0,0,0,
	//0,0,0,0,
	//1,0,0,0,
	//0,0,0,0,
	//0,0,0,0,
	//0,0,0,0,
	//0,0,0,0,
	//
	0,0,0,0,
	0,0,0,0,
	0,0,0,1,
	0,0,0,1,
	1,0,0,0,
	0,0,0,0,
	0,0,0,0,
	//
	//0,0,0,0,
	//0,0,0,0,
	//1,0,0,0,
	//0,0,0,0,
	//0,0,0,0,
	//0,0,0,0,
	//0,0,0,0,
	////
	//0,0,0,0,
	//0,0,0,0,
	//1,0,0,0,
	//0,0,0,0,
	//0,0,0,0,
	//0,0,0,0,
	//0,0,0,0,
	////
	//0,0,0,0,
	//0,0,0,0,
	//1,0,0,0,
	//0,0,0,0,
	//0,0,0,0,
	//0,0,0,0,
	//0,0,0,0,
	////
	//0,0,0,0,
	//0,0,0,0,
	//1,0,0,0,
	//0,0,0,0,
	//0,0,0,0,
	//0,0,0,0,
	//0,0,0,0,
	//
	//1,1,1,1,
	//1,1,1,1,
	//1,1,1,1,
	//1,1,1,1,
	//1,1,1,1,
	//1,1,1,1,
	//1,1,1,1
	//
	//1,1,1,1,
	//1,1,1,1,
	//1,1,1,1,
	//1,1,1,1,
	//1,1,1,1,
	//1,1,1,1,
	//1,1,1,1
	//
	//1,1,1,1,
	//1,1,1,1,
	//1,1,1,1,
	//1,1,1,1,
	//1,1,1,1,
	//1,1,1,1,
	//1,1,1,1
	//
	//1,1,1,1,
	//1,1,1,1,
	//1,1,1,1,
	//1,1,1,1,
	//1,1,1,1,
	//1,1,1,1,
	//1,1,1,1
	//
	//1,1,1,1,
	//1,1,1,1,
	//1,1,1,1,
	//1,1,1,1,
	//1,1,1,1,
	//1,1,1,1,
	//1,1,1,1
	//
	//1,1,1,1,
	//1,1,1,1,
	//1,1,1,1,
	//1,1,1,1,
	//1,1,1,1,
	//1,1,1,1,
	//1,1,1,1
	//
	//1,1,1,1,
	//1,1,1,1,
	//1,1,1,1,
	//1,1,1,1,
	//1,1,1,1,
	//1,1,1,1,
	//1,1,1,1
};

void high(int _pin){
	pinMode(_pin, OUTPUT);
	digitalWrite(_pin, HIGH);
}

//void com_to_avg(){
	//pinMode(_pin, INPUT_PULLUP);
//}

void disconnect(int _pin){
	pinMode(_pin, INPUT); /* set pin as input */
	digitalWrite(_pin, LOW); /* set to 0 in input mode */
}

void low(int _pin){
	pinMode(_pin, OUTPUT);
	digitalWrite(_pin, LOW);
}
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

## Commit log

2018-11-15 Initial commit.
    [Gears.scad, combos.csv, housing.scad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]
2019-03-14 Fixed dst offset.
    [layout.scad]
2020-12-17 Added thumbnail images.
    [base.scad, base.stl, light_mask_test_20180911.stl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]
2020-12-27 Cleaned up code formatting. Fixed DST setting. Removed obsolete docs.
    [CPPLINT.cfg, combos.csv, pins.csv]
2021-01-17 Updated stl images.
    [housing.stl, layout.scad, lens_holder_bottom.stl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]
2022-04-12 Update README.md
    Added link to specific lens used.
2023-06-09 Fixed Windowsisms in the ino
    [firmware.ino]
